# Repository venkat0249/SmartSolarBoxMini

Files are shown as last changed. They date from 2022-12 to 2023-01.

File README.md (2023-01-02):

# SmartSolarBoxMini

Smart Solar Box is a smart and intelligent solar power storage unit with monitoring and control capabilities.This is an education project designed for kids and students to learn about Solar photovoltaic energy and battery technology. The smart solar box is composed of a power system and an information system. It has four main elements: SSB mini PCB, ESP8266 D1 Mini, a solar panel, and a battery. 

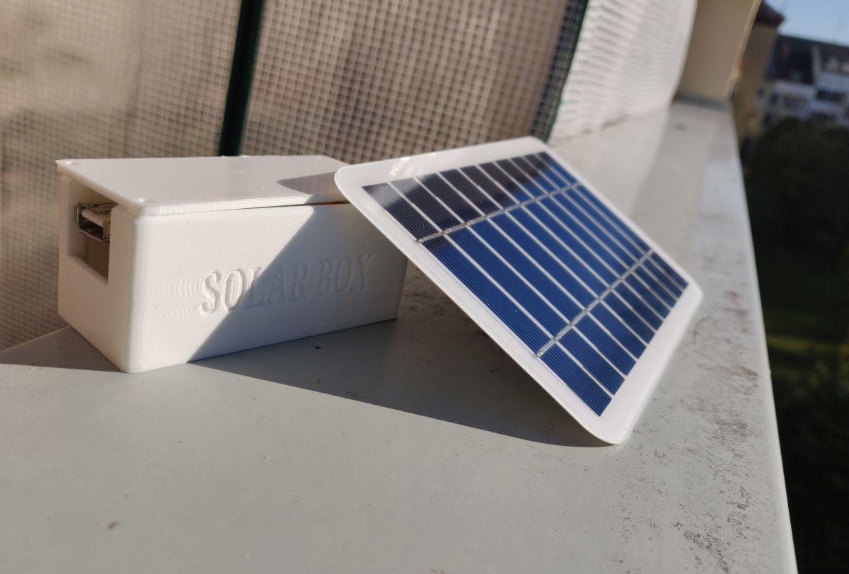
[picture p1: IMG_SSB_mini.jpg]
ssb


The solar panel absorbs solar radiation and turns it into direct-current electricity. SSB mini PCB consists of Battery charger IC that takes care of battery charging process. Boost converter converts battery voltage to 5V regulated output. INA3221 power monitoring IC monitors the power flow. ESP D1 mini communicates with SSB Mini PCB and runs the Solar Box live dashboard. D1 mini get the power from SSB mini pcb power line. ESP mini creates its own wifi hotspot so that smart phones/laptops could be connected and access the dashboard easily. 

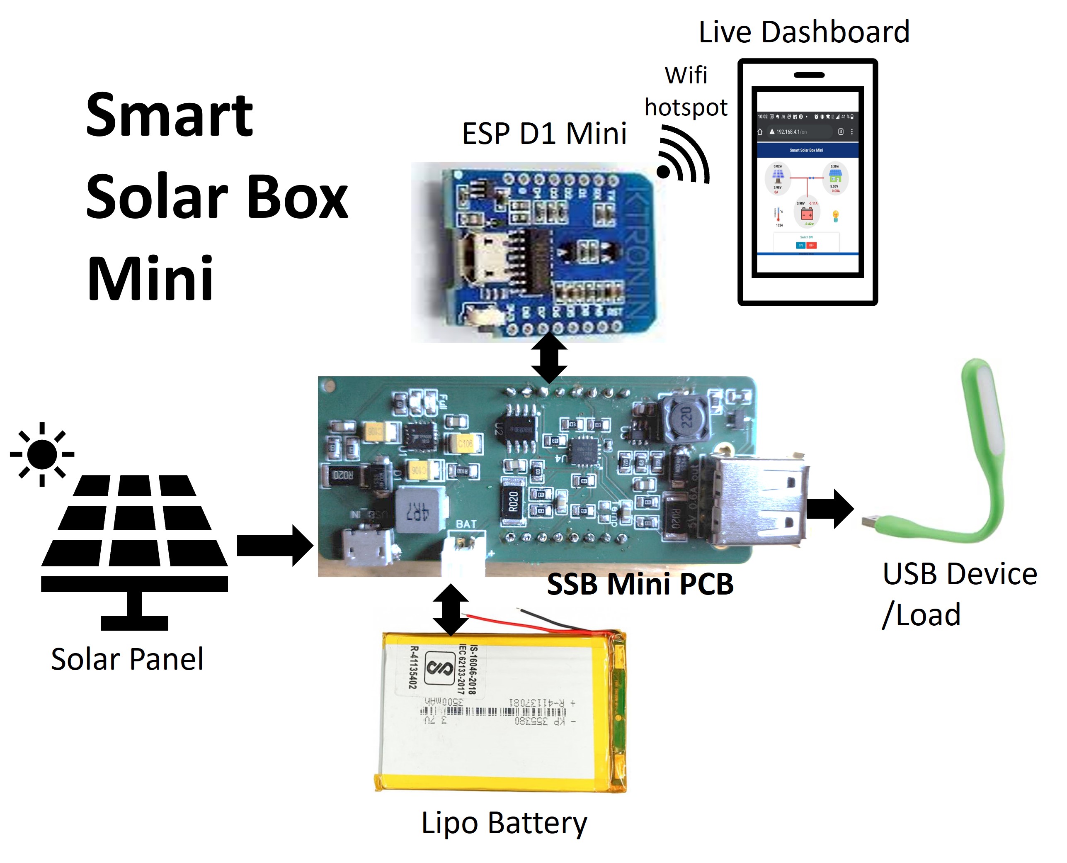
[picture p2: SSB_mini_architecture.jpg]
ssbArchitecture


This project aims at kids and students to learn about solar energy and battery storage technologies. Using the live monitoring dashboard, students can observe the power flow and readings. Activity and experiment sheets help students learn about various concepts related to sustainable energy, battery storage and solar energy.

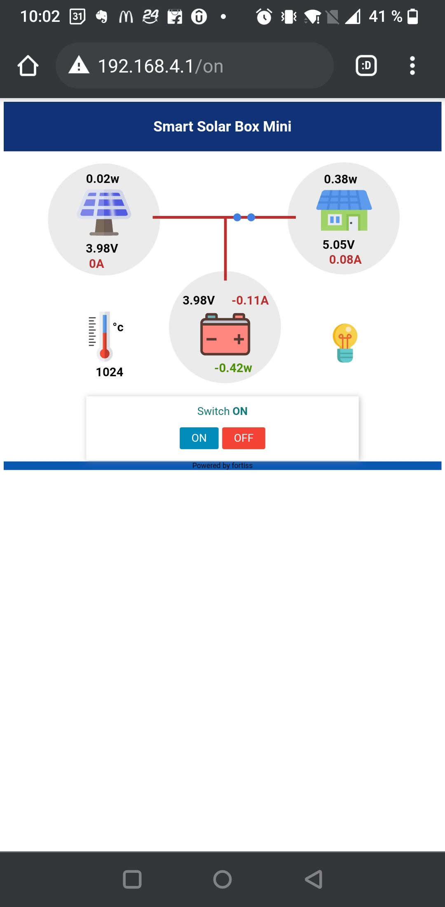
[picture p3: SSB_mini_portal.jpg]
ssb_portal


Resources for pcb manufacturing and other required parts are present in "Hardware" folder

## Challenges:

- Component selection and BOM reduction was quite challenging as the project can be realized using various power management ICs and microcontrollers. Due to chip shortage, keeping the cost of the kit low and availability of major components were another major challenges. By Comparing huge list of components/IC iin the market in terms of their availability, prices and realiability, final BOM were selected and schematics were designed. 
- Writing a reliable code for Solar monitoring and control dashboard
- Various tests were performed in order to make it is safe to use and easy to assemble for kids.

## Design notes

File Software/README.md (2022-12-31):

# SmartSolarBoxMini

>ssb mini assembled pics<

- Resources for pcb manufacturing and other required parts are present in "Hardware" folder

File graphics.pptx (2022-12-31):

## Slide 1


Smart Solar Box Mini

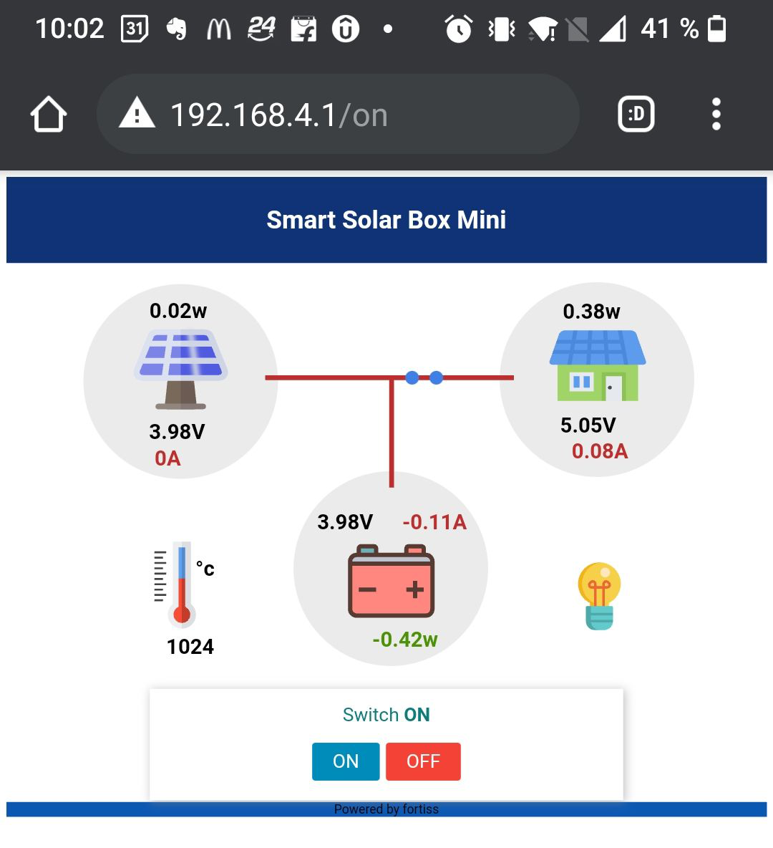
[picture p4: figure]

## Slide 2

Live Dashboard

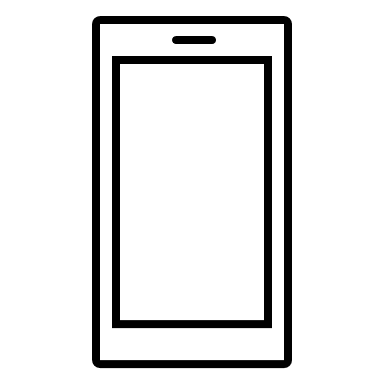
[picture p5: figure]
Smart Phone outline

Smart Solar Box Mini

ESP D1 Mini

Wifi hotspot

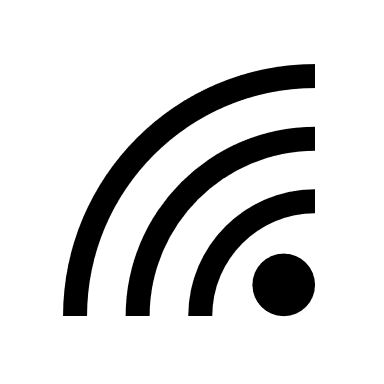
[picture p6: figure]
Wireless with solid fill
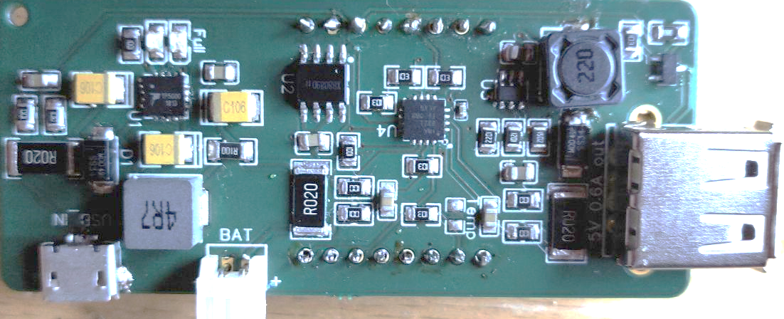
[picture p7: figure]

SSB Mini PCB

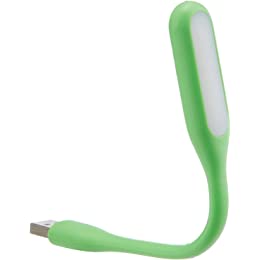
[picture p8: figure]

USB Device /Load

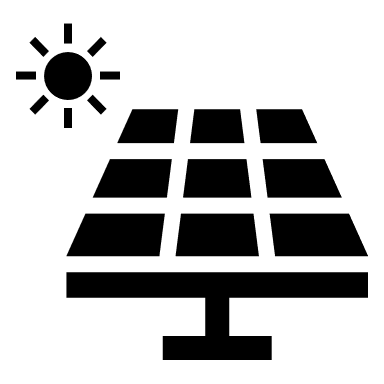
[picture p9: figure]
Solar Panels with solid fill

Solar Panel

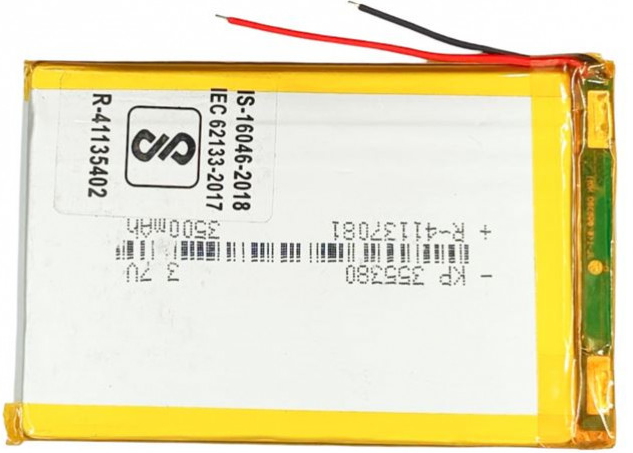
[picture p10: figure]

Lipo Battery

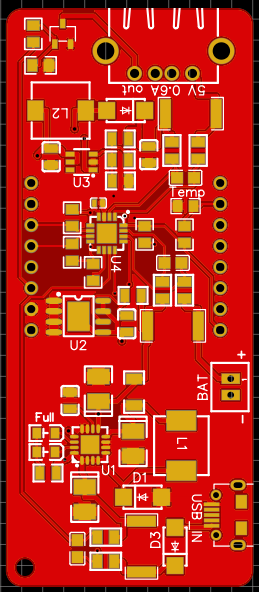
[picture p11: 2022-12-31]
Hardware/pcb_front.PNG

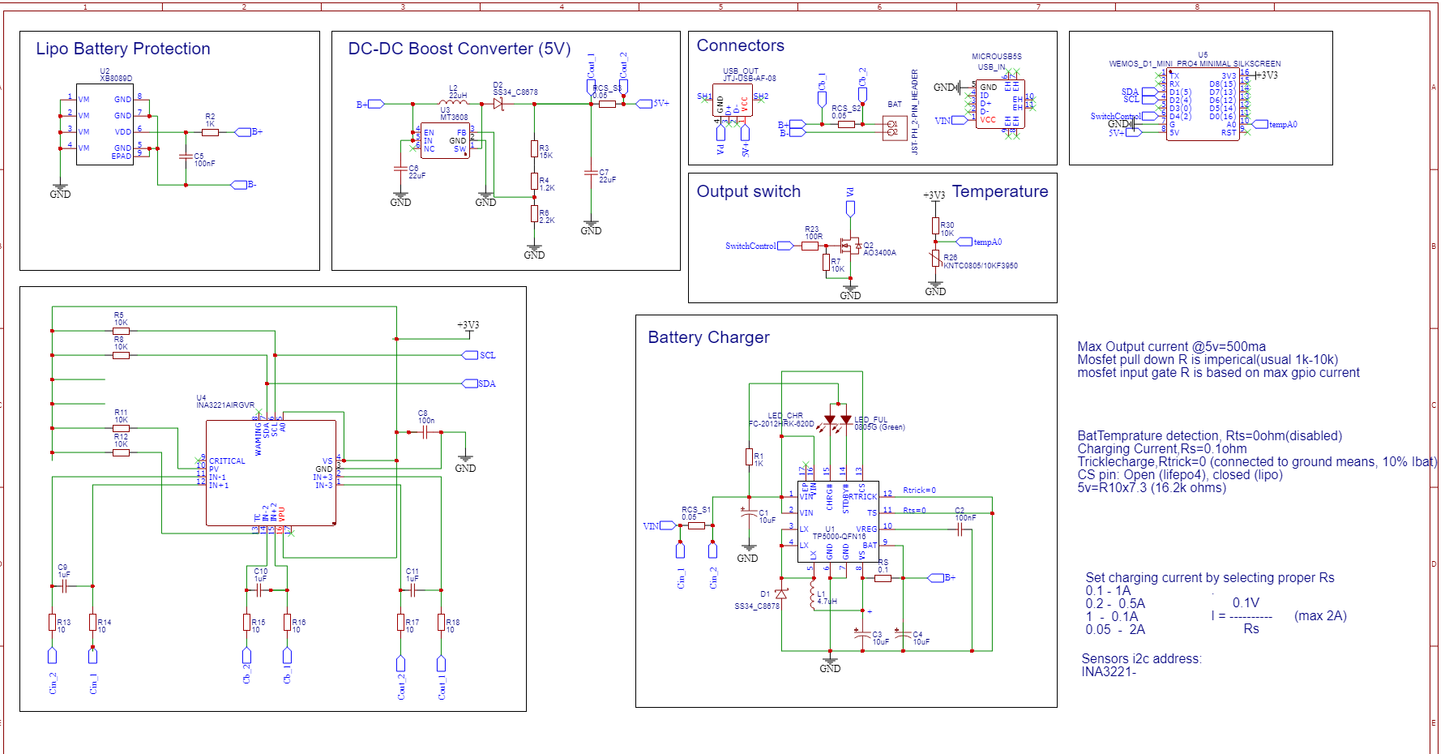
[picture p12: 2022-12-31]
Hardware/Schematic_SmartSolarBox_Mini_v2.png

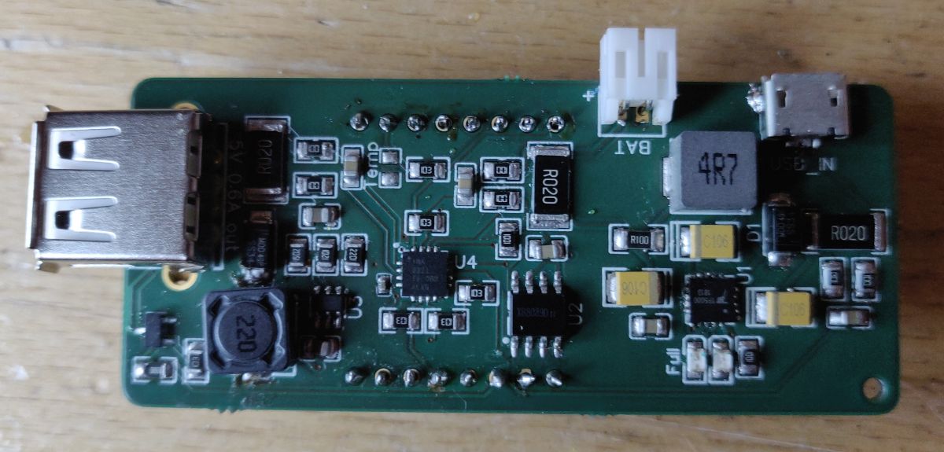
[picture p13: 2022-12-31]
IMG_SSB_mini_pcb_front.jpg

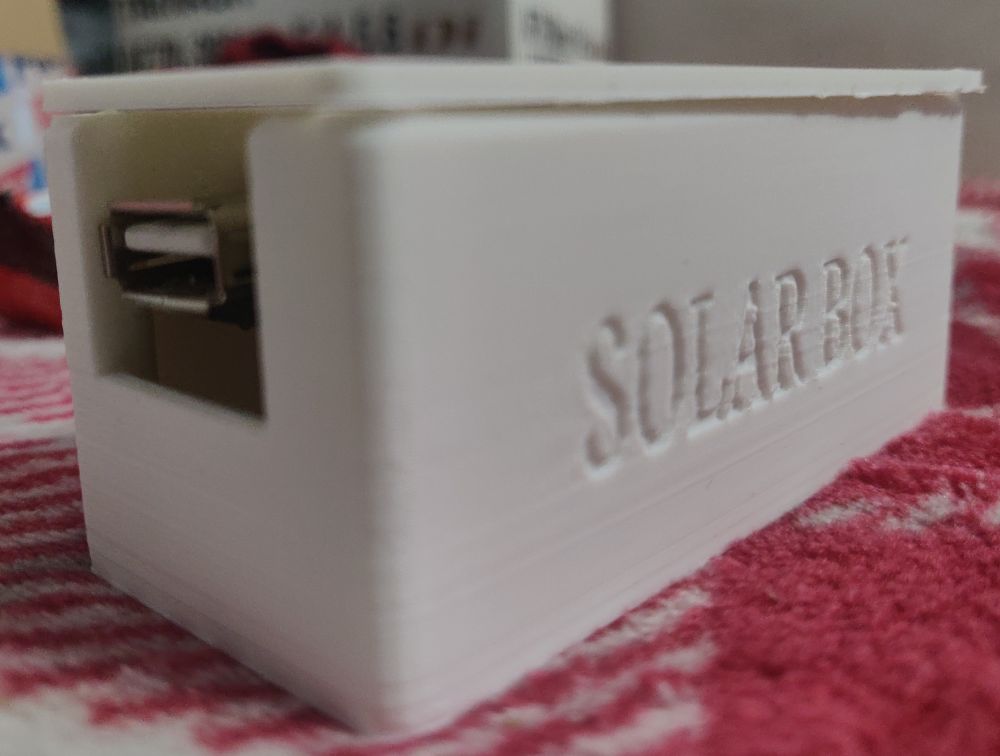
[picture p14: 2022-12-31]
IMG_SSB_mini2.jpg

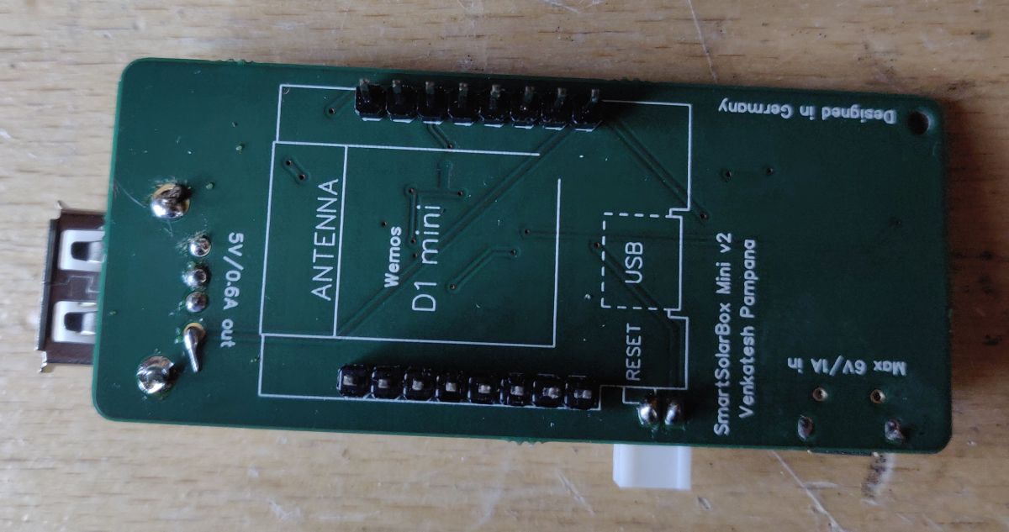
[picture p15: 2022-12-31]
SSB_mini_pcb_back.jpg

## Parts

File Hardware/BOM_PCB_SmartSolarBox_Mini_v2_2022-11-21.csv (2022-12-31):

ID | Name | Designator | Footprint | Quantity | Manufacturer Part | Manufacturer | Price
1 | JST-PH_2-PIN_HEADER | BAT | JST_B2B-PH_HEADER | 1
2 | 10uF | C1,C3,C4 | CAP-SMD_L3.5-W2.8-R-RD | 3 | 293D106X9020B2TE3 | VISHAY | 0.041
3 | 100nF | C2,C5 | C0805 | 2 | CC0805KRX7R9BB104 | YAGEO | 0.001
4 | 22uF | C6,C7 | C0805 | 2 | CL21A226MAQNNNE | SAMSUNG | 0.004
5 | 100n | C8 | C0402 | 1 | CC0402KRX7R7BB104 | YAGEO
6 | 1uF | C9,C10,C11 | C0805 | 3 | CC0805KKX7R8BB105 | YAGEO | 0.002
7 | SS34_C8678 | D1,D2,D3 | DO-214AC_L4.3-W2.7-LS5.3-RD | 3 | SS34 | MDD | 0.005
8 | 4.7uH | L1 | IND-SMD_L7.1-W6.6 | 1 | SMMS0650-4R7M | SXN | 0.031
9 | 22uH | L2 | IND-SMD_L7.0-W6.8 | 1 | SMRH74-220MT | SXN | 0.03
10 | FC-2012HRK-620D | LED_CHR | LED0805-RD | 1 | FC-2012HRK-620D | NATIONSTAR | 0.002
11 | 0805G (Green) | LED_FUL | LED0805-RD | 1 | 0805G (Green) | KENTO
12 | AO3400A | Q2 | SOT-23-3_L2.9-W1.6-P1.90-LS2.8-BR | 1 | AO3400A | AOS | 0.018
13 | 1K | R1,R2 | R0805 | 2 | 0805W8F1001T5E | UniOhm
14 | 15K | R3 | R0805 | 1 | 0805W8F1502T5E | UniOhm
15 | 1.2K | R4 | R0805 | 1 | 0805W8F1201T5E | UniOhm
16 | 10K | R5,R7,R8,R11,R12,R30 | 0805 | 6 | 0805W8J0103T5E | UniOhm
17 | 2.2K | R6 | R0805 | 1 | 0805W8F2201T5E | UniOhm
18 | 10 | R13,R14,R15,R16,R17,R18 | 805 | 6 | ?
19 | 100R | R23 | 0805 | 1 | 0805W8F1000T5E | UniOhm
20 | KNTC0805/10KF3950 | R26 | R0805 | 1 | KNTC0805/10KF3950 | KUU | 0.006
21 | 0.05 | RCS_S1,RCS_S2,RCS_S3 | R2512 | 3 | MRF6432(2512)LR050FTS | SUP | 0.016
22 | 0.1 | RS | R1206 | 1 | 1206W4F100LT5E | UniOhm | 0.001
23 | TP5000-QFN16 | U1 | QFN-16_L4.0-W4.0-P0.65-BL-EP2.2 | 1 | TP5000-QFN16 | TOPPOWER | 0.057
24 | XB8089D | U2 | SOIC-8_L5.0-W4.0-P1.27-LS6.0-BL-EP | 1 | XB8089D | Xysemi | 0.029
25 | MT3608 | U3 | SOT-23-6_L2.9-W1.6-P0.95-LS2.8-BR | 1 | MT3608 | AEROSEMI | 0.02
26 | INA3221AIRGVR | U4 | QFN-16-4MMX4MM | 1 | INA3221AIRGVR | Texas Instruments | 0.507
27 | WEMOS_D1_MINI_PRO4 MINIMAL SILKSCREEN | U5 | DIP-16_WEMOS_D1_MINI_PRO4 | 1 | Wemos_D1_mini_Pro4 | null
28 | MICROUSB5S | USB_IN | MICRO-USB_MICRO-USB-5S | 1 | MICROUSB5S | null
29 | JTJ-USB-AF-08 | USB_OUT | USB-A-TH__USB-AF-90 | 1 | JTJ-USB-AF-08 |  | 0.008

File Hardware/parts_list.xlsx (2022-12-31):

part | link-1 | link-2
5v mini solar panel (1-5 watts) | https://www.reichelt.com/de/en/solar-panel-for-nedis-cameras-n-solch10wt-p337242.html?trstct=pos_10&nbc=1
Lipo battery with JST PH2.0 socket (3.7 V 800mah -1800 mah) | https://www.reichelt.com/de/en/lipo-battery-for-mbot-amp-halocode-3-75-v-1800-mah-mb-lipo-mbot-p260190.html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 | https://www.ebay.de/itm/274335252550
D1 Mini ESP8266 | https://www.reichelt.com/de/en/d1-mini-esp8266-v2-0-d1-mini-p253978.html

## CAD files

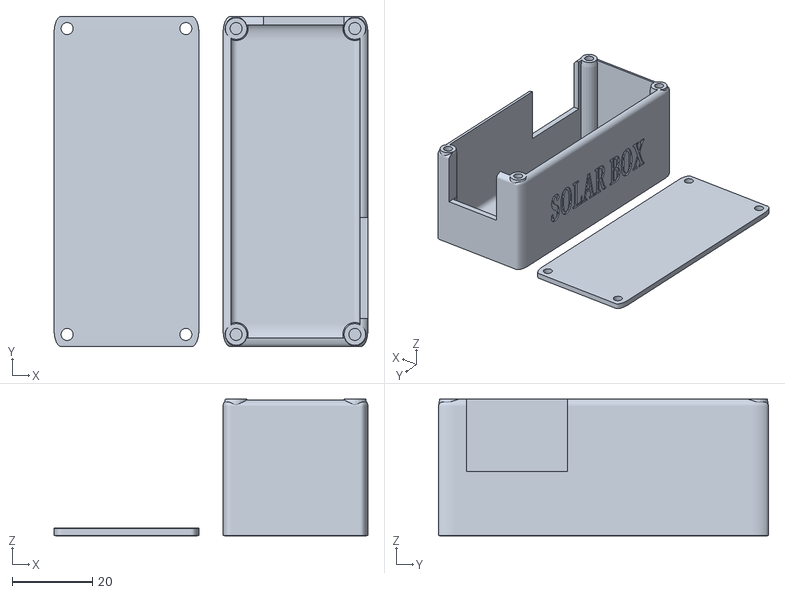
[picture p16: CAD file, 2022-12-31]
Hardware/ssb_mini_3dprint.stl
78.0 x 82.0 x 34.0

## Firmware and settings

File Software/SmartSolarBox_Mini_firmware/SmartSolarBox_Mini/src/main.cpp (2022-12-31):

/*********
  Author- Venkatesh Pampana
  Complete project details at 
*********/

// Import required libraries
#include <Arduino.h>
#include <ESP8266WiFi.h>
#include <Hash.h>
#include <ESPAsyncTCP.h>
#include <ESPAsyncWebServer.h>
#include "LittleFS.h"
#include <SDL_Arduino_INA3221.h>

const char* ssid     = "SSB_Mini_wifi";
const char* password = "123456789";

#define LIPO_BATTERY_CHANNEL 2
#define SOLAR_CELL_CHANNEL 1
#define OUTPUT_CHANNEL 3
//address and shunt resistor value
SDL_Arduino_INA3221 ina3221(0x41,0.02);
//SensirionI2CSht4x shtSensor;
// current temperature & humidity, updated in loop()
float temperature = 0.0;
float humidity = 0.0;

unsigned long previousMillis = 0; 
unsigned long interval = 1000;  
// Create AsyncWebServer object on port 80
AsyncWebServer server(80);
AsyncWebSocket ws("/ws");
//Adafruit_SHT4x sht4xSensor = Adafruit_SHT4x();
//12v output switch control pin
const uint8 outSwitchPin = 2;
const uint8 anlogPin = 0;
//char errorMessage[256];
String switchState;
String statusmsg;
String getTemperature() {
  // uint16_t error;
  // error = shtSensor.measureMediumPrecision(temperature, humidity);
  //     if (error) {
  //       Serial.print("Error : ");
  //       errorToString(error, errorMessage, 256);
  //       Serial.println(errorMessage);
  //     }
  // Read temperature as Fahrenheit (isFahrenheit = true)
  //float temperature = 1.8 * bme.readTemperature() + 32;
  //Serial.println(temperature);
  return String(temperature);
}
  
String getHumidity() {
  //float humidity = bme.readHumidity();
  Serial.println(humidity);
  return String(humidity);
}

String getReadings() {

  float inAmps = ina3221.getCurrent_mA(SOLAR_CELL_CHANNEL)/1000;
  float batAmps = ina3221.getCurrent_mA(LIPO_BATTERY_CHANNEL)/1000;  //  + means the battery is charging, - that it is
  float loadAmps = ina3221.getCurrent_mA(OUTPUT_CHANNEL)/1000;
  float inVolts=ina3221.getBusVoltage_V(SOLAR_CELL_CHANNEL);
  float batVolts=ina3221.getBusVoltage_V(LIPO_BATTERY_CHANNEL);
  float loadVolts=ina3221.getBusVoltage_V(OUTPUT_CHANNEL);
  float inPow =inAmps*inVolts;
  float batPow =batAmps*batVolts;
  float LoadPow =loadAmps*loadVolts;
  float temperature =analogRead(anlogPin);
  //Serial.println(pressure);
  return String("{\"sa\":" +String(inAmps)+",\"sv\":"+inVolts+",\"sp\":"+inPow+",\"bv\":"+batVolts+",\"ba\":"+batAmps+
  ",\"bs\":"+batPow+",\"lv\":"+loadVolts+",\"la\":"+loadAmps+",\"lp\":"+LoadPow+",\"temp\":"+temperature+"}");

}
// Replaces placeholder with sensor values
String processor(const String& var){
  //Serial.println(var);
  if(var == "STATE"){
    if(digitalRead(outSwitchPin)){
      switchState = "ON";                    
    }
    else{
      switchState = "OFF";
    }
    Serial.print(switchState);
    return switchState;
  }
  return String();
}


void setup() {
  // put your setup code here, to run once:
  Serial.begin(9600);

  // Initialize LittleFS
  if (!LittleFS.begin()) {
    Serial.println("An error has occurred while mounting LittleFS");
  }
  Serial.println("LittleFS mounted successfully");


  Serial.print("Setting AP (Access Point)…");
  // Remove the password parameter, if you want the AP (Access Point) to be open
  WiFi.softAP(ssid, password);

  IPAddress IP = WiFi.softAPIP();
  Serial.print("AP IP address: ");
  Serial.println(IP);

  // Print ESP8266 Local IP Address
  Serial.println(WiFi.localIP());
  //set  output switch pin mode
  pinMode(outSwitchPin, OUTPUT);
  digitalWrite(outSwitchPin, HIGH);
  ina3221.begin();

  Serial.println(ina3221.getManufID(),HEX);
      //initialize wire library (used for sht4x sensor)
  Wire.begin(5,4);
  //shtSensor.begin(Wire);
  //uint32_t serialNumber;
  //shtSensor.serialNumber(serialNumber);
 // Serial.println(serialNumber);
  // Route for root / web page
  server.on("/", HTTP_GET, [](AsyncWebServerRequest *request){
    request->send(LittleFS, "/index.html", String(), false, processor);
  });
  
  // Route to load style.css file
  server.on("/style.css", HTTP_GET, [](AsyncWebServerRequest *request){
    request->send(LittleFS, "/style.css", "text/css");
  });

    // Route to load js file
  server.on("/jquery-3.3.1.min.js", HTTP_GET, [](AsyncWebServerRequest *request){
    request->send(LittleFS, "/jquery-3.3.1.min.js", "text/css");
  });

    // Route to load img file (not working)
  // server.on("/solarboxlogo_header", HTTP_GET, [](AsyncWebServerRequest *request){
  //   request->send(LittleFS, "/solarboxlogo_header.png", "image/png");
  // });

      // Route to load img file
  server.on("/ssb_dashboard_final_v1.svg", HTTP_GET, [](AsyncWebServerRequest *request){
    request->send(LittleFS, "/ssb_dashboard_final_v1.svg", "image/svg+xml");
  });

  // Route to set GPIO to HIGH
  server.on("/on", HTTP_GET, [](AsyncWebServerRequest *request){
    digitalWrite(outSwitchPin, HIGH);    
    request->send(LittleFS, "/index.html", String(), false, processor);
  });
  
  // Route to set GPIO to LOW
  server.on("/off", HTTP_GET, [](AsyncWebServerRequest *request){
    digitalWrite(outSwitchPin, LOW);    
    request->send(LittleFS, "/index.html", String(), false, processor);
  });

  //   server.on("/temperature", HTTP_GET, [](AsyncWebServerRequest *request){
  //   request->send_P(200, "text/plain", getTemperature().c_str());
  // });
  
  server.on("/humidity", HTTP_GET, [](AsyncWebServerRequest *request){
    request->send_P(200, "text/plain", getHumidity().c_str());
  });
  server.addHandler(&ws);
  // Start server
  server.begin();
}

void loop() {

unsigned long currentMillis = millis();
  if (currentMillis - previousMillis >= interval) {
    // save the last time you updated the DHT values
    previousMillis = currentMillis;
  ws.textAll(getReadings());
  ws.cleanupClients();

  } 
}
